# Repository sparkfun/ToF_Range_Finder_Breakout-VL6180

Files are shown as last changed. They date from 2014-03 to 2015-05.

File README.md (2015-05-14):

SparkFun ToF Range Finder Breakout - VL6180
===========================================

SparkFun ToF Range Finder Breakout - VL6180

[*SparkFun ToF Range Finder Breakout - VL6180 (SEN-12784)*](https://www.sparkfun.com/products/12784)

This is a breakout board for the VL6180 Baby Bear time of flight range finder.
The VL6180 is actually a 3-in-1 package that combines an IR emitter, a range sensor, and an ambient light sensor together for you to easily use. 

Repository Contents
-------------------
* **/Hardware** - All Eagle design files (.brd, .sch)
* **/Libraries** - All Arduino libraries and board examples
* **/Production** - Test bed files and production panel files

Documentation
--------------
* **[Library](https://github.com/sparkfun/SparkFun_ToF_Range_Finder-VL6180_Arduino_Library)** - Arduino  library for the VL6180.
* **[Hookup Guide](https://learn.sparkfun.com/tutorials/vl6180-hookup-guide)** - Basic hookup guide for the VL6180.
* **[SparkFun Fritzing repo](https://github.com/sparkfun/Fritzing_Parts)** - Fritzing diagrams for SparkFun products.
* **[SparkFun 3D Model repo](https://github.com/sparkfun/3D_Models)** - 3D models of SparkFun products. 

License Information
-------------------
This product is _**open source**_! 

The **hardware** is released under [Creative Commons ShareAlike 4.0 International](https://creativecommons.org/licenses/by-sa/4.0/).

The **code** is beerware; if you see me (or any other SparkFun employee) at the local, and you've found our code helpful, please buy us a round!

Please use, reuse, and modify these files as you see fit. Please maintain attribution to SparkFun Electronics and release anything derivative under the same license.

Distributed as-is; no warranty is given.

- Your friends at SparkFun.

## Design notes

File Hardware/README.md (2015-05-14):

SparkFun <PRODUCT NAME> Design Files
=====================================

The .sch and .brd files hare are Eagle CAD schematic and PCB design files from SparkFun Electronics.
A freeware version of Eagle can be found [here](http://www.cadsoftusa.com/download-eagle/freeware/). 

License
---------
This product is open source! 
The hardware is released under [Creative Commons ShareAlike 4.0 International](https://creativecommons.org/licenses/by-sa/4.0/).

Please use, reuse, and modify these files as you see fit. Please maintain attribution to SparkFun Electronics and release anything derivative under the same license.

Distributed as-is; no warranty is given.

- Your friends at SparkFun.

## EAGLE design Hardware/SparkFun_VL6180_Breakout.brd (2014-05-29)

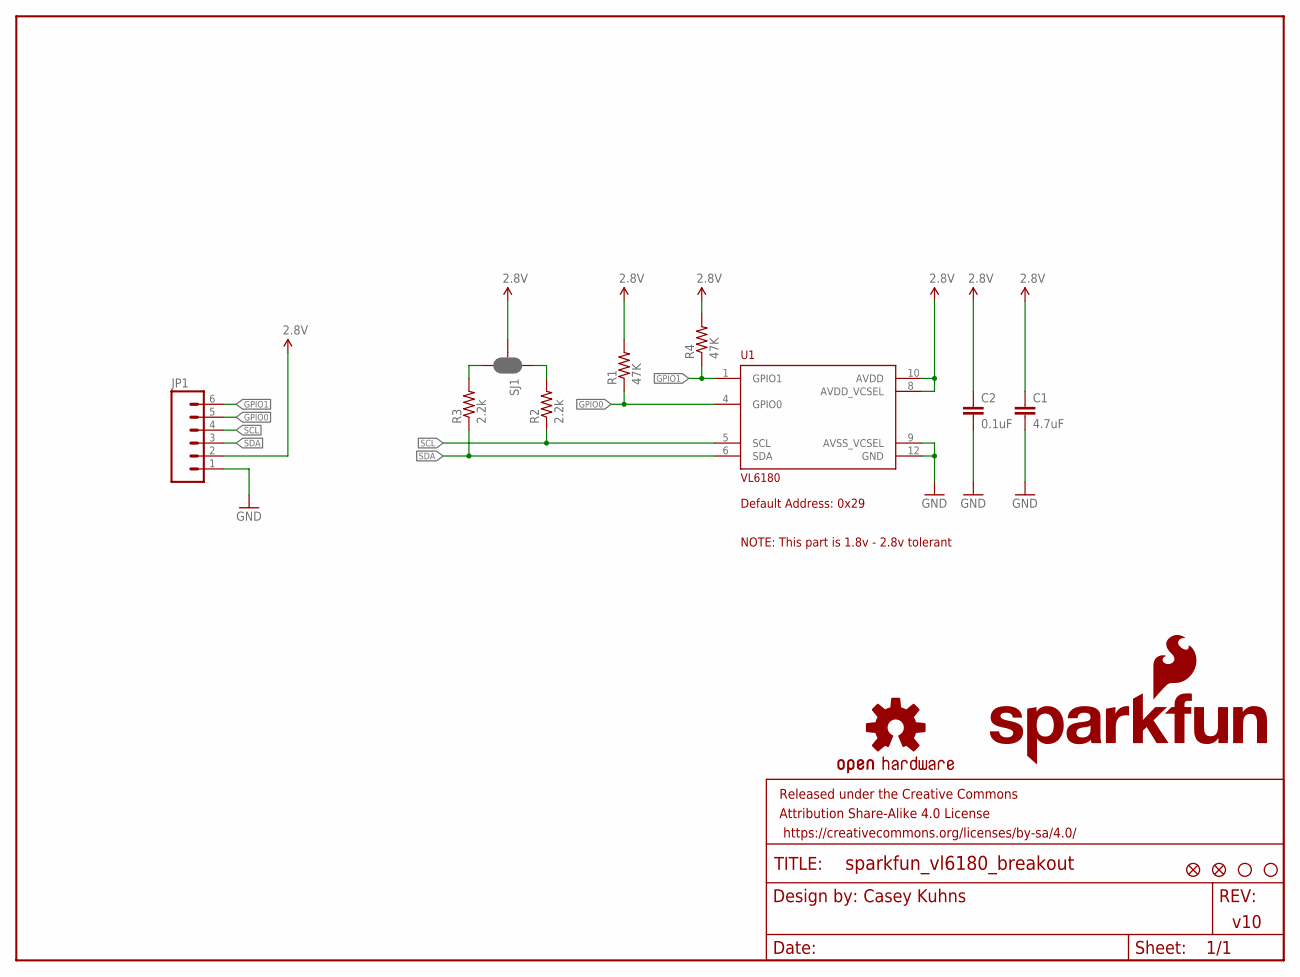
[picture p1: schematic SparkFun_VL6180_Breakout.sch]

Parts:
C1: 4.7uF; 0603-CAP
C2: 0.1uF; 0603-CAP
FID1, FID2: FIDUCIAL1X2; FIDUCIAL-1X2
FRAME1: FRAME-LETTER; CREATIVE_COMMONS
JP1: M06SIP; 1X06
LOGO1: SFE_LOGO_NAME_FLAME.1_INCH; SFE_LOGO_NAME_FLAME_.1
LOGO2: OSHW-LOGOS; OSHW-LOGO-S
R1, R4: 47K; 0603-RES
R2, R3: 2.2k; 0603-RES
SJ1: JUMPER-PAD-3-NC_BY_PASTE; PAD-JUMPER-3-NC_BY_PASTE_YES_SILK_FULL_BOX
STANDOFF1, STANDOFF2: STAND-OFF
U1: VL6180

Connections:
2.8V: C1.1, C2.1, JP1.2, R1.2, R4.2, SJ1.2, U1.8 (AVDD_VCSEL), U1.10 (AVDD)
GND: C1.2, C2.2, JP1.1, U1.9 (AVSS_VCSEL), U1.12 (GND)
GPIO0: JP1.5, R1.1, U1.4 (GPIO0)
GPIO1: JP1.6, R4.1, U1.1 (GPIO1)
unnamed: R2.2, SJ1.1
unnamed: R3.2, SJ1.3
SCL: JP1.4, R2.1, U1.5 (SCL)
SDA: JP1.3, R3.1, U1.6 (SDA)

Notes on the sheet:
Casey Kuhns
v10
Default Address: 0x29
NOTE: This part is 1.8v - 2.8v tolerant

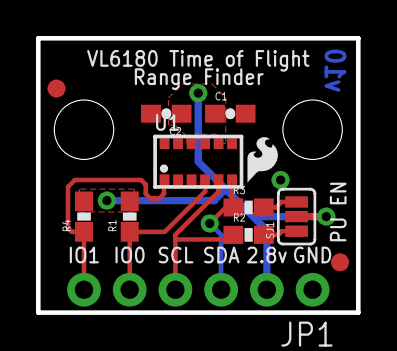
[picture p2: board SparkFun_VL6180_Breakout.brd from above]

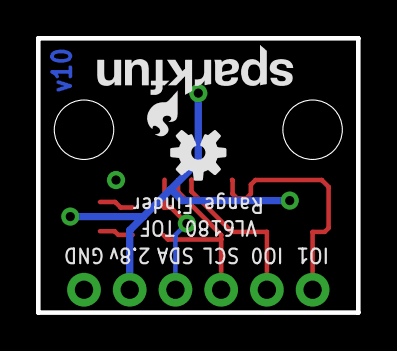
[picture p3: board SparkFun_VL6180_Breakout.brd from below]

Board: 2 copper layers, 17.8 x 15.2 mm, 17 parts (2 on the bottom side), 8 nets.

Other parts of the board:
U$2: SFE_LOGO_FLAME_.1

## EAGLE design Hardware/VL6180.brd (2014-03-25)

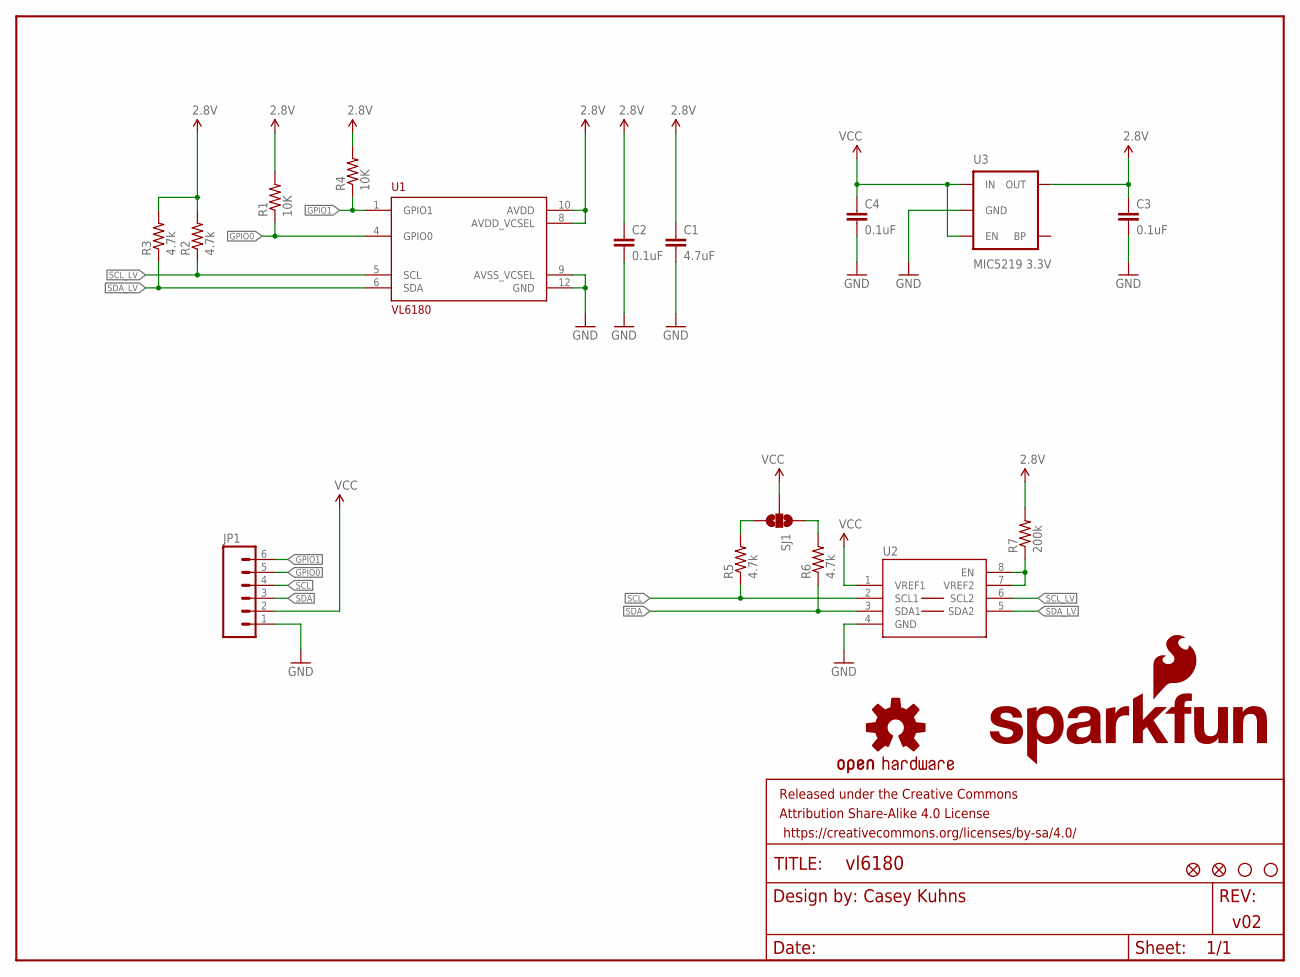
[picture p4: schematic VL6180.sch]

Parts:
C1: 4.7uF; 0603-CAP
C2, C3, C4: 0.1uF; 0603-CAP
FID1, FID2: FIDUCIAL1X2; FIDUCIAL-1X2
FRAME1: FRAME-LETTER; CREATIVE_COMMONS
JP1: M06SIP; 1X06
LOGO1: SFE_LOGO_NAME_FLAME.1_INCH; SFE_LOGO_NAME_FLAME_.1
LOGO2: OSHW-LOGOS; OSHW-LOGO-S
R1, R4: 10K; 0603-RES
R2, R3, R5, R6: 4.7k; 0603
R7: 200k; 0603-RES
SJ1: SOLDERJUMPER_2WAYPASTE1&2&3; SJ_3_PASTE1&2&3
STANDOFF1, STANDOFF2: STAND-OFF
U1: VL6180
U2: PCA9306; PSOP-8
U3: MIC5219 3.3V; SOT23-5

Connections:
2.8V: C1.1, C2.1, C3.1, R1.2, R2.2, R3.2, R4.2, R7.2, U1.8 (AVDD_VCSEL), U1.10 (AVDD), U3.5 (OUT)
GND: C1.2, C2.2, C3.2, C4.2, JP1.1, U1.9 (AVSS_VCSEL), U1.12 (GND), U2.4 (GND), U3.2 (GND)
GPIO0: JP1.5, R1.1, U1.4 (GPIO0)
GPIO1: JP1.6, R4.1, U1.1 (GPIO1)
unnamed: R7.1, U2.7 (VREF2), U2.8 (EN)
unnamed: R6.2, SJ1.1
unnamed: R5.2, SJ1.3
SCL: JP1.4, R5.1, U2.2 (SCL1)
SCL_LV: R2.1, U1.5 (SCL), U2.6 (SCL2)
SDA: JP1.3, R6.1, U2.3 (SDA1)
SDA_LV: R3.1, U1.6 (SDA), U2.5 (SDA2)
VCC: C4.1, JP1.2, SJ1.2, U2.1 (VREF1), U3.1 (IN), U3.3 (EN)

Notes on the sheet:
Casey Kuhns
v02

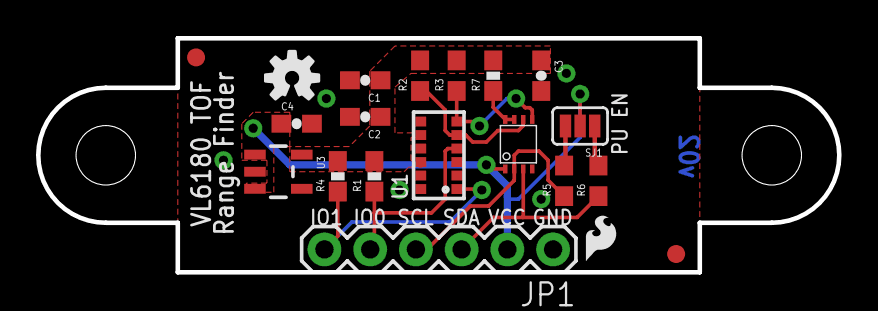
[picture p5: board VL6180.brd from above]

Board: 2 copper layers, 44.5 x 13.0 mm, 24 parts (1 on the bottom side), 12 nets.

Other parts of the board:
U$2: SFE_LOGO_FLAME_.1

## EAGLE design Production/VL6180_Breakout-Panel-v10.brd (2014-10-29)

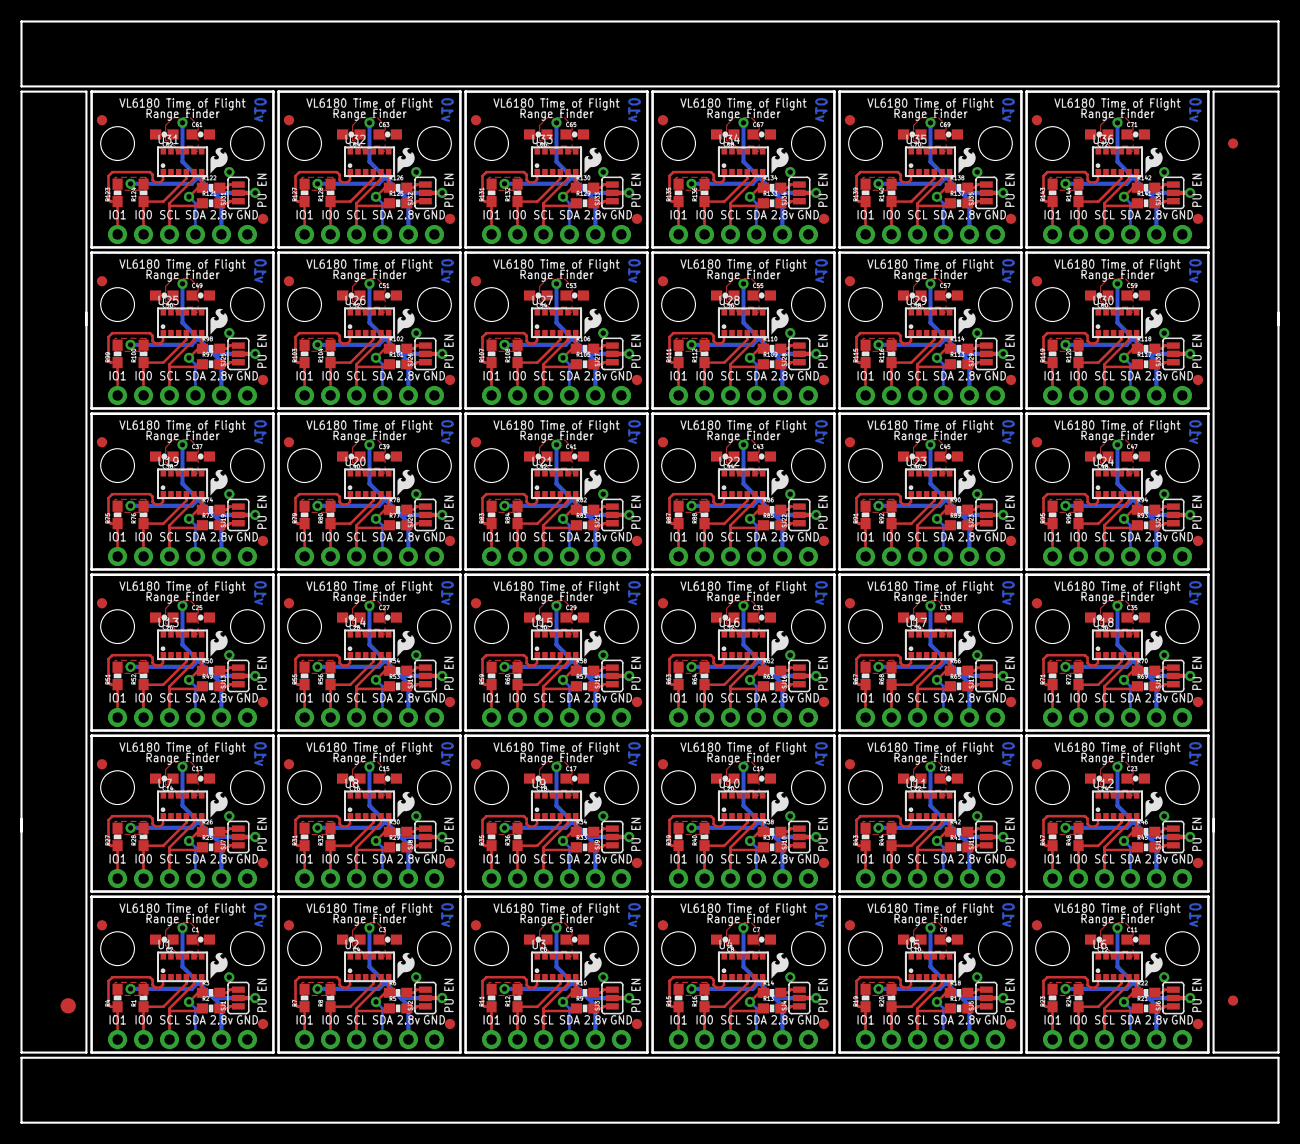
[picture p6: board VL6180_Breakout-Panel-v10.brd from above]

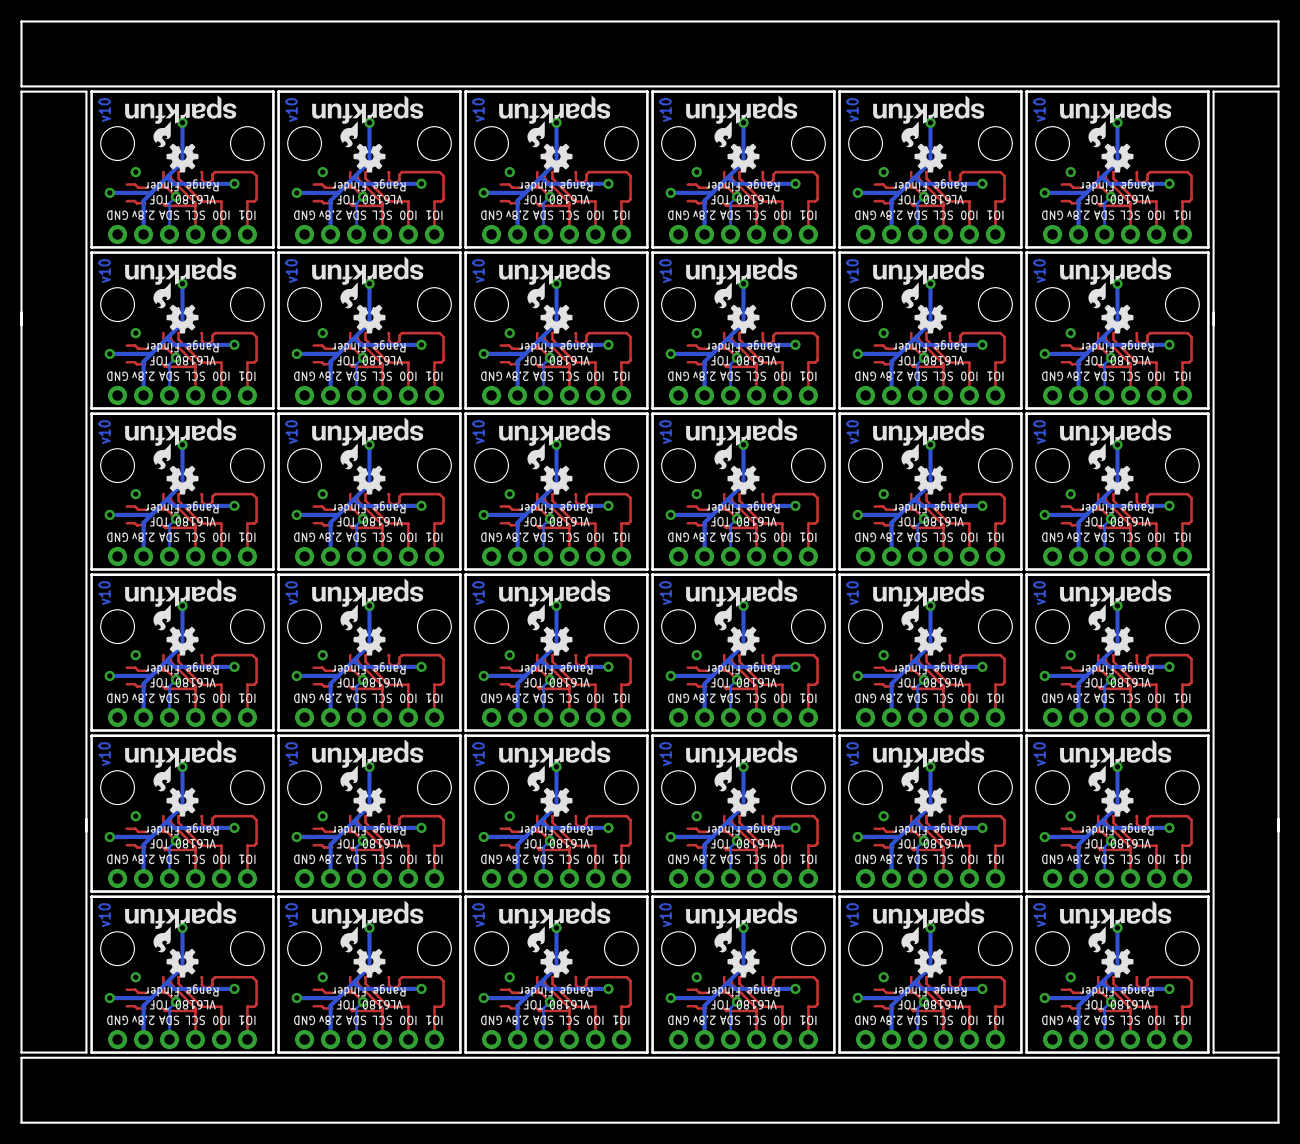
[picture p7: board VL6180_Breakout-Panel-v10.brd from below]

Board: 2 copper layers, 122.9 x 107.7 mm, 579 parts (72 on the bottom side), 288 nets.

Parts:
C1, C3, C5, C7, C9, C11, C13, C15, C17, C19, C21, C23, C25, C27, C29, C31, C33, C35, C37, C39, C41, C43, C45, C47, C49, C51, C53, C55, C57, C59, C61, C63, C65, C67, C69, C71: 4.7uF; 0603-CAP
C2, C4, C6, C8, C10, C12, C14, C16, C18, C20, C22, C24, C26, C28, C30, C32, C34, C36, C38, C40, C42, C44, C46, C48, C50, C52, C54, C56, C58, C60, C62, C64, C66, C68, C70, C72: 0.1uF; 0603-CAP
E$1: FIDUCIAL-1.5X3
E$4, E$6: FIDUCIAL-1X2
FID1, FID2, FID3, FID4, FID5, FID6, FID7, FID8, FID9, FID10, FID11, FID12, FID13, FID14, FID15, FID16, FID17, FID18, FID19, FID20, FID21, FID22, FID23, FID24, FID25, FID26, FID27, FID28, FID29, FID30, FID31, FID32, FID33, FID34, FID35, FID36, FID37, FID38, FID39, FID40, FID41, FID42, FID43, FID44, FID45, FID46, FID47, FID48, FID49, FID50, FID51, FID52, FID53, FID54, FID55, FID56, FID57, FID58, FID59, FID60, FID61, FID62, FID63, FID64, FID65, FID66, FID67, FID68, FID69, FID70, FID71, FID72: FIDUCIAL1X2; FIDUCIAL-1X2
JP1, JP2, JP3, JP4, JP5, JP6, JP7, JP8, JP9, JP10, JP11, JP12, JP13, JP14, JP15, JP16, JP17, JP18, JP19, JP20, JP21, JP22, JP23, JP24, JP25, JP26, JP27, JP28, JP29, JP30, JP31, JP32, JP33, JP34, JP35, JP36: 1X06
LOGO1, LOGO3, LOGO5, LOGO7, LOGO9, LOGO11, LOGO13, LOGO15, LOGO17, LOGO19, LOGO21, LOGO23, LOGO25, LOGO27, LOGO29, LOGO31, LOGO33, LOGO35, LOGO37, LOGO39, LOGO41, LOGO43, LOGO45, LOGO47, LOGO49, LOGO51, LOGO53, LOGO55, LOGO57, LOGO59, LOGO61, LOGO63, LOGO65, LOGO67, LOGO69, LOGO71: SFE_LOGO_NAME_FLAME.1_INCH; SFE_LOGO_NAME_FLAME_.1
LOGO2, LOGO4, LOGO6, LOGO8, LOGO10, LOGO12, LOGO14, LOGO16, LOGO18, LOGO20, LOGO22, LOGO24, LOGO26, LOGO28, LOGO30, LOGO32, LOGO34, LOGO36, LOGO38, LOGO40, LOGO42, LOGO44, LOGO46, LOGO48, LOGO50, LOGO52, LOGO54, LOGO56, LOGO58, LOGO60, LOGO62, LOGO64, LOGO66, LOGO68, LOGO70, LOGO72: OSHW-LOGOS; OSHW-LOGO-S
R1, R4, R7, R8, R11, R12, R15, R16, R19, R20, R23, R24, R27, R28, R31, R32, R35, R36, R39, R40, R43, R44, R47, R48, R51, R52, R55, R56, R59, R60, R63, R64, R67, R68, R71, R72, R75, R76, R79, R80, R83, R84, R87, R88, R91, R92, R95, R96, R99, R100, R103, R104, R107, R108, R111, R112, R115, R116, R119, R120, R123, R124, R127, R128, R131, R132, R135, R136, R139, R140, R143, R144: 47K; 0603-RES
R2, R3, R5, R6, R9, R10, R13, R14, R17, R18, R21, R22, R25, R26, R29, R30, R33, R34, R37, R38, R41, R42, R45, R46, R49, R50, R53, R54, R57, R58, R61, R62, R65, R66, R69, R70, R73, R74, R77, R78, R81, R82, R85, R86, R89, R90, R93, R94, R97, R98, R101, R102, R105, R106, R109, R110, R113, R114, R117, R118, R121, R122, R125, R126, R129, R130, R133, R134, R137, R138, R141, R142: 2.2k; 0603-RES
SJ1, SJ2, SJ3, SJ4, SJ5, SJ6, SJ7, SJ8, SJ9, SJ10, SJ11, SJ12, SJ13, SJ14, SJ15, SJ16, SJ17, SJ18, SJ19, SJ20, SJ21, SJ22, SJ23, SJ24, SJ25, SJ26, SJ27, SJ28, SJ29, SJ30, SJ31, SJ32, SJ33, SJ34, SJ35, SJ36: PAD-JUMPER-3-NC_BY_PASTE_YES_SILK_FULL_BOX
STANDOFF1, STANDOFF2, STANDOFF3, STANDOFF4, STANDOFF5, STANDOFF6, STANDOFF7, STANDOFF8, STANDOFF9, STANDOFF10, STANDOFF11, STANDOFF12, STANDOFF13, STANDOFF14, STANDOFF15, STANDOFF16, STANDOFF17, STANDOFF18, STANDOFF19, STANDOFF20, STANDOFF21, STANDOFF22, STANDOFF23, STANDOFF24, STANDOFF25, STANDOFF26, STANDOFF27, STANDOFF28, STANDOFF29, STANDOFF30, STANDOFF31, STANDOFF32, STANDOFF33, STANDOFF34, STANDOFF35, STANDOFF36, STANDOFF37, STANDOFF38, STANDOFF39, STANDOFF40, STANDOFF41, STANDOFF42, STANDOFF43, STANDOFF44, STANDOFF45, STANDOFF46, STANDOFF47, STANDOFF48, STANDOFF49, STANDOFF50, STANDOFF51, STANDOFF52, STANDOFF53, STANDOFF54, STANDOFF55, STANDOFF56, STANDOFF57, STANDOFF58, STANDOFF59, STANDOFF60, STANDOFF61, STANDOFF62, STANDOFF63, STANDOFF64, STANDOFF65, STANDOFF66, STANDOFF67, STANDOFF68, STANDOFF69, STANDOFF70, STANDOFF71, STANDOFF72: STAND-OFF
U1, U2, U3, U4, U5, U6, U7, U8, U9, U10, U11, U12, U13, U14, U15, U16, U17, U18, U19, U20, U21, U22, U23, U24, U25, U26, U27, U28, U29, U30, U31, U32, U33, U34, U35, U36: VL6180
U$1, U$2, U$3, U$4, U$5, U$6, U$7, U$8, U$9, U$10, U$11, U$12, U$13, U$14, U$15, U$16, U$17, U$18, U$19, U$20, U$21, U$22, U$23, U$24, U$25, U$26, U$27, U$28, U$29, U$30, U$31, U$32, U$33, U$34, U$35, U$36: SFE_LOGO_FLAME_.1

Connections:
2.8V: C1.1, C2.1, JP1.2, R1.2, R4.2, SJ1.2, U1.8, U1.10
2.8V1: C3.1, C4.1, JP2.2, R7.2, R8.2, SJ2.2, U2.8, U2.10
2.8V2: C5.1, C6.1, JP3.2, R11.2, R12.2, SJ3.2, U3.8, U3.10
2.8V3: C7.1, C8.1, JP4.2, R15.2, R16.2, SJ4.2, U4.8, U4.10
2.8V4: C9.1, C10.1, JP5.2, R19.2, R20.2, SJ5.2, U5.8, U5.10
2.8V5: C11.1, C12.1, JP6.2, R23.2, R24.2, SJ6.2, U6.8, U6.10
2.8V6: C13.1, C14.1, JP7.2, R27.2, R28.2, SJ7.2, U7.8, U7.10
2.8V7: C15.1, C16.1, JP8.2, R31.2, R32.2, SJ8.2, U8.8, U8.10
2.8V8: C17.1, C18.1, JP9.2, R35.2, R36.2, SJ9.2, U9.8, U9.10
2.8V9: C19.1, C20.1, JP10.2, R39.2, R40.2, SJ10.2, U10.8, U10.10
2.8V10: C21.1, C22.1, JP11.2, R43.2, R44.2, SJ11.2, U11.8, U11.10
2.8V11: C23.1, C24.1, JP12.2, R47.2, R48.2, SJ12.2, U12.8, U12.10
2.8V12: C25.1, C26.1, JP13.2, R51.2, R52.2, SJ13.2, U13.8, U13.10
2.8V13: C27.1, C28.1, JP14.2, R55.2, R56.2, SJ14.2, U14.8, U14.10
2.8V14: C29.1, C30.1, JP15.2, R59.2, R60.2, SJ15.2, U15.8, U15.10
2.8V15: C31.1, C32.1, JP16.2, R63.2, R64.2, SJ16.2, U16.8, U16.10
2.8V16: C33.1, C34.1, JP17.2, R67.2, R68.2, SJ17.2, U17.8, U17.10
2.8V17: C35.1, C36.1, JP18.2, R71.2, R72.2, SJ18.2, U18.8, U18.10
2.8V18: C37.1, C38.1, JP19.2, R75.2, R76.2, SJ19.2, U19.8, U19.10
2.8V19: C39.1, C40.1, JP20.2, R79.2, R80.2, SJ20.2, U20.8, U20.10
2.8V20: C41.1, C42.1, JP21.2, R83.2, R84.2, SJ21.2, U21.8, U21.10
2.8V21: C43.1, C44.1, JP22.2, R87.2, R88.2, SJ22.2, U22.8, U22.10
2.8V22: C45.1, C46.1, JP23.2, R91.2, R92.2, SJ23.2, U23.8, U23.10
2.8V23: C47.1, C48.1, JP24.2, R95.2, R96.2, SJ24.2, U24.8, U24.10
2.8V24: C49.1, C50.1, JP25.2, R99.2, R100.2, SJ25.2, U25.8, U25.10
2.8V25: C51.1, C52.1, JP26.2, R103.2, R104.2, SJ26.2, U26.8, U26.10
2.8V26: C53.1, C54.1, JP27.2, R107.2, R108.2, SJ27.2, U27.8, U27.10
2.8V27: C55.1, C56.1, JP28.2, R111.2, R112.2, SJ28.2, U28.8, U28.10
2.8V28: C57.1, C58.1, JP29.2, R115.2, R116.2, SJ29.2, U29.8, U29.10
2.8V29: C59.1, C60.1, JP30.2, R119.2, R120.2, SJ30.2, U30.8, U30.10
2.8V30: C61.1, C62.1, JP31.2, R123.2, R124.2, SJ31.2, U31.8, U31.10
2.8V31: C63.1, C64.1, JP32.2, R127.2, R128.2, SJ32.2, U32.8, U32.10
2.8V32: C65.1, C66.1, JP33.2, R131.2, R132.2, SJ33.2, U33.8, U33.10
2.8V33: C67.1, C68.1, JP34.2, R135.2, R136.2, SJ34.2, U34.8, U34.10
2.8V34: C69.1, C70.1, JP35.2, R139.2, R140.2, SJ35.2, U35.8, U35.10
2.8V35: C71.1, C72.1, JP36.2, R143.2, R144.2, SJ36.2, U36.8, U36.10
GND: C1.2, C2.2, JP1.1, U1.9, U1.12
GND1: C3.2, C4.2, JP2.1, U2.9, U2.12
GND2: C5.2, C6.2, JP3.1, U3.9, U3.12
GND3: C7.2, C8.2, JP4.1, U4.9, U4.12
GND4: C9.2, C10.2, JP5.1, U5.9, U5.12
GND5: C11.2, C12.2, JP6.1, U6.9, U6.12
GND6: C13.2, C14.2, JP7.1, U7.9, U7.12
GND7: C15.2, C16.2, JP8.1, U8.9, U8.12
GND8: C17.2, C18.2, JP9.1, U9.9, U9.12
GND9: C19.2, C20.2, JP10.1, U10.9, U10.12
GND10: C21.2, C22.2, JP11.1, U11.9, U11.12
GND11: C23.2, C24.2, JP12.1, U12.9, U12.12
GND12: C25.2, C26.2, JP13.1, U13.9, U13.12
GND13: C27.2, C28.2, JP14.1, U14.9, U14.12
GND14: C29.2, C30.2, JP15.1, U15.9, U15.12
GND15: C31.2, C32.2, JP16.1, U16.9, U16.12
GND16: C33.2, C34.2, JP17.1, U17.9, U17.12
GND17: C35.2, C36.2, JP18.1, U18.9, U18.12
GND18: C37.2, C38.2, JP19.1, U19.9, U19.12
GND19: C39.2, C40.2, JP20.1, U20.9, U20.12
GND20: C41.2, C42.2, JP21.1, U21.9, U21.12
GND21: C43.2, C44.2, JP22.1, U22.9, U22.12
GND22: C45.2, C46.2, JP23.1, U23.9, U23.12
GND23: C47.2, C48.2, JP24.1, U24.9, U24.12
GND24: C49.2, C50.2, JP25.1, U25.9, U25.12
GND25: C51.2, C52.2, JP26.1, U26.9, U26.12
GND26: C53.2, C54.2, JP27.1, U27.9, U27.12
GND27: C55.2, C56.2, JP28.1, U28.9, U28.12
GND28: C57.2, C58.2, JP29.1, U29.9, U29.12
GND29: C59.2, C60.2, JP30.1, U30.9, U30.12
GND30: C61.2, C62.2, JP31.1, U31.9, U31.12
GND31: C63.2, C64.2, JP32.1, U32.9, U32.12
GND32: C65.2, C66.2, JP33.1, U33.9, U33.12
GND33: C67.2, C68.2, JP34.1, U34.9, U34.12
GND34: C69.2, C70.2, JP35.1, U35.9, U35.12
GND35: C71.2, C72.2, JP36.1, U36.9, U36.12
GPIO0: JP1.5, R1.1, U1.4
GPIO1: JP1.6, R4.1, U1.1
GPIO2: JP2.5, R8.1, U2.4
GPIO3: JP2.6, R7.1, U2.1
GPIO4: JP3.5, R12.1, U3.4
GPIO5: JP3.6, R11.1, U3.1
GPIO6: JP4.5, R16.1, U4.4
GPIO7: JP4.6, R15.1, U4.1
GPIO8: JP5.5, R20.1, U5.4
GPIO9: JP5.6, R19.1, U5.1
GPIO10: JP6.5, R24.1, U6.4
GPIO11: JP6.6, R23.1, U6.1
GPIO12: JP7.5, R28.1, U7.4
GPIO13: JP7.6, R27.1, U7.1
GPIO14: JP8.5, R32.1, U8.4
GPIO15: JP8.6, R31.1, U8.1
GPIO16: JP9.5, R36.1, U9.4
GPIO17: JP9.6, R35.1, U9.1
GPIO18: JP10.5, R40.1, U10.4
GPIO19: JP10.6, R39.1, U10.1
GPIO20: JP11.5, R44.1, U11.4
GPIO21: JP11.6, R43.1, U11.1
GPIO22: JP12.5, R48.1, U12.4
GPIO23: JP12.6, R47.1, U12.1
GPIO24: JP13.5, R52.1, U13.4
GPIO25: JP13.6, R51.1, U13.1
GPIO26: JP14.5, R56.1, U14.4
GPIO27: JP14.6, R55.1, U14.1
GPIO28: JP15.5, R60.1, U15.4
GPIO29: JP15.6, R59.1, U15.1
GPIO30: JP16.5, R64.1, U16.4
GPIO31: JP16.6, R63.1, U16.1
GPIO32: JP17.5, R68.1, U17.4
GPIO33: JP17.6, R67.1, U17.1
GPIO34: JP18.5, R72.1, U18.4
GPIO35: JP18.6, R71.1, U18.1
GPIO36: JP19.5, R76.1, U19.4
GPIO37: JP19.6, R75.1, U19.1
GPIO38: JP20.5, R80.1, U20.4
GPIO39: JP20.6, R79.1, U20.1
GPIO40: JP21.5, R84.1, U21.4
GPIO41: JP21.6, R83.1, U21.1
GPIO42: JP22.5, R88.1, U22.4
GPIO43: JP22.6, R87.1, U22.1
GPIO44: JP23.5, R92.1, U23.4
GPIO45: JP23.6, R91.1, U23.1
GPIO46: JP24.5, R96.1, U24.4
GPIO47: JP24.6, R95.1, U24.1
GPIO48: JP25.5, R100.1, U25.4
GPIO49: JP25.6, R99.1, U25.1
GPIO50: JP26.5, R104.1, U26.4
GPIO51: JP26.6, R103.1, U26.1
GPIO52: JP27.5, R108.1, U27.4
GPIO53: JP27.6, R107.1, U27.1
GPIO54: JP28.5, R112.1, U28.4
GPIO55: JP28.6, R111.1, U28.1
GPIO56: JP29.5, R116.1, U29.4
GPIO57: JP29.6, R115.1, U29.1
GPIO58: JP30.5, R120.1, U30.4
GPIO59: JP30.6, R119.1, U30.1
GPIO60: JP31.5, R124.1, U31.4
GPIO61: JP31.6, R123.1, U31.1
GPIO62: JP32.5, R128.1, U32.4
GPIO63: JP32.6, R127.1, U32.1
GPIO64: JP33.5, R132.1, U33.4
GPIO65: JP33.6, R131.1, U33.1
GPIO66: JP34.5, R136.1, U34.4
GPIO67: JP34.6, R135.1, U34.1
GPIO68: JP35.5, R140.1, U35.4
GPIO69: JP35.6, R139.1, U35.1
GPIO70: JP36.5, R144.1, U36.4
GPIO71: JP36.6, R143.1, U36.1
unnamed: R2.2, SJ1.1
unnamed: R3.2, SJ1.3
unnamed: R5.2, SJ2.1
unnamed: R6.2, SJ2.3
unnamed: R9.2, SJ3.1
unnamed: R10.2, SJ3.3
unnamed: R13.2, SJ4.1
unnamed: R14.2, SJ4.3
unnamed: R17.2, SJ5.1
unnamed: R18.2, SJ5.3
unnamed: R21.2, SJ6.1
unnamed: R22.2, SJ6.3
unnamed: R25.2, SJ7.1
unnamed: R26.2, SJ7.3
unnamed: R29.2, SJ8.1
unnamed: R30.2, SJ8.3
unnamed: R33.2, SJ9.1
unnamed: R34.2, SJ9.3
unnamed: R37.2, SJ10.1
unnamed: R38.2, SJ10.3
unnamed: R41.2, SJ11.1
unnamed: R42.2, SJ11.3
unnamed: R45.2, SJ12.1
unnamed: R46.2, SJ12.3
unnamed: R49.2, SJ13.1
unnamed: R50.2, SJ13.3
unnamed: R53.2, SJ14.1
unnamed: R54.2, SJ14.3
unnamed: R57.2, SJ15.1
unnamed: R58.2, SJ15.3
unnamed: R61.2, SJ16.1
unnamed: R62.2, SJ16.3
unnamed: R65.2, SJ17.1
unnamed: R66.2, SJ17.3
unnamed: R69.2, SJ18.1
unnamed: R70.2, SJ18.3
unnamed: R73.2, SJ19.1
unnamed: R74.2, SJ19.3
unnamed: R77.2, SJ20.1
unnamed: R78.2, SJ20.3
unnamed: R81.2, SJ21.1
unnamed: R82.2, SJ21.3
unnamed: R85.2, SJ22.1
unnamed: R86.2, SJ22.3
unnamed: R89.2, SJ23.1
unnamed: R90.2, SJ23.3
unnamed: R93.2, SJ24.1
unnamed: R94.2, SJ24.3
unnamed: R97.2, SJ25.1
unnamed: R98.2, SJ25.3
unnamed: R101.2, SJ26.1
unnamed: R102.2, SJ26.3
unnamed: R105.2, SJ27.1
unnamed: R106.2, SJ27.3
unnamed: R109.2, SJ28.1
unnamed: R110.2, SJ28.3
unnamed: R113.2, SJ29.1
unnamed: R114.2, SJ29.3
unnamed: R117.2, SJ30.1
unnamed: R118.2, SJ30.3
unnamed: R121.2, SJ31.1
unnamed: R122.2, SJ31.3
unnamed: R125.2, SJ32.1
unnamed: R126.2, SJ32.3
unnamed: R129.2, SJ33.1
unnamed: R130.2, SJ33.3
unnamed: R133.2, SJ34.1
unnamed: R134.2, SJ34.3
unnamed: R137.2, SJ35.1
unnamed: R138.2, SJ35.3
unnamed: R141.2, SJ36.1
unnamed: R142.2, SJ36.3
SCL: JP1.4, R2.1, U1.5
SCL1: JP2.4, R5.1, U2.5
SCL2: JP3.4, R9.1, U3.5
SCL3: JP4.4, R13.1, U4.5
SCL4: JP5.4, R17.1, U5.5
SCL5: JP6.4, R21.1, U6.5
SCL6: JP7.4, R25.1, U7.5
SCL7: JP8.4, R29.1, U8.5
SCL8: JP9.4, R33.1, U9.5
SCL9: JP10.4, R37.1, U10.5
SCL10: JP11.4, R41.1, U11.5
SCL11: JP12.4, R45.1, U12.5
SCL12: JP13.4, R49.1, U13.5
SCL13: JP14.4, R53.1, U14.5
SCL14: JP15.4, R57.1, U15.5
SCL15: JP16.4, R61.1, U16.5
SCL16: JP17.4, R65.1, U17.5
SCL17: JP18.4, R69.1, U18.5
SCL18: JP19.4, R73.1, U19.5
SCL19: JP20.4, R77.1, U20.5
SCL20: JP21.4, R81.1, U21.5
SCL21: JP22.4, R85.1, U22.5
SCL22: JP23.4, R89.1, U23.5
SCL23: JP24.4, R93.1, U24.5
SCL24: JP25.4, R97.1, U25.5
SCL25: JP26.4, R101.1, U26.5
SCL26: JP27.4, R105.1, U27.5
SCL27: JP28.4, R109.1, U28.5
SCL28: JP29.4, R113.1, U29.5
SCL29: JP30.4, R117.1, U30.5
SCL30: JP31.4, R121.1, U31.5
SCL31: JP32.4, R125.1, U32.5
SCL32: JP33.4, R129.1, U33.5
SCL33: JP34.4, R133.1, U34.5
SCL34: JP35.4, R137.1, U35.5
SCL35: JP36.4, R141.1, U36.5
SDA: JP1.3, R3.1, U1.6
SDA1: JP2.3, R6.1, U2.6
SDA2: JP3.3, R10.1, U3.6
SDA3: JP4.3, R14.1, U4.6
SDA4: JP5.3, R18.1, U5.6
SDA5: JP6.3, R22.1, U6.6
SDA6: JP7.3, R26.1, U7.6
SDA7: JP8.3, R30.1, U8.6
SDA8: JP9.3, R34.1, U9.6
SDA9: JP10.3, R38.1, U10.6
SDA10: JP11.3, R42.1, U11.6
SDA11: JP12.3, R46.1, U12.6
SDA12: JP13.3, R50.1, U13.6
SDA13: JP14.3, R54.1, U14.6
SDA14: JP15.3, R58.1, U15.6
SDA15: JP16.3, R62.1, U16.6
SDA16: JP17.3, R66.1, U17.6
SDA17: JP18.3, R70.1, U18.6
SDA18: JP19.3, R74.1, U19.6
SDA19: JP20.3, R78.1, U20.6
SDA20: JP21.3, R82.1, U21.6
SDA21: JP22.3, R86.1, U22.6
SDA22: JP23.3, R90.1, U23.6
SDA23: JP24.3, R94.1, U24.6
SDA24: JP25.3, R98.1, U25.6
SDA25: JP26.3, R102.1, U26.6
SDA26: JP27.3, R106.1, U27.6
SDA27: JP28.3, R110.1, U28.6
SDA28: JP29.3, R114.1, U29.6
SDA29: JP30.3, R118.1, U30.6
SDA30: JP31.3, R122.1, U31.6
SDA31: JP32.3, R126.1, U32.6
SDA32: JP33.3, R130.1, U33.6
SDA33: JP34.3, R134.1, U34.6
SDA34: JP35.3, R138.1, U35.6
SDA35: JP36.3, R142.1, U36.6

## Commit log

2014-02-21 initial commit with initial hardware layout
    [VL6180.brd, VL6180.sch]
2014-02-28 Boad Layout finished, looking for review
    [VL6180.brd, VL6180.sch]
2014-03-03 finished layout and added simple breakout board layout
    [VL6180_Breakout.brd, VL6180_Breakout.sch]
2014-03-03 changed VCC label on breakout to 2.8v to re-state 2.8v compatible
    [VL6180_Breakout.brd]
2014-03-04 Changed I2C EN to PU EN
    [VL6180.brd, VL6180_Breakout.brd]
2014-03-13 fixed flipped pin problem. 8-9 on the sensor were reversed somehow. All better :)
    [VL6180.brd, VL6180.sch, VL6180_Breakout.brd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]
2014-03-25 added pin 1 designator
    [VL6180.brd, VL6180.sch, VL6180_Breakout.brd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]
2014-05-01 modified: Hardware/VL6180_Breakout.brd modified: Hardware/VL6180_Breakout.sch renamed: Hardware/VL6180.brd -> Hardware/VL6180_Sensor.brd renamed: Hardware/VL6180.sch -> Hardware/VL6180_Sensor.sch
    Removed I2C level shifter and switched to Fet bases solution.
    New solderpaste footprint for VL6180 for improved reflow.
    updated all parts with Sparkle ID's
    [VL6180_Breakout.brd, VL6180_Breakout.sch, VL6180_Sensor.brd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]
2014-05-28 changed I2C resistors to 2.2k, added current limiting resistor on GPIO pins.
    [VL6180_Breakout.brd, VL6180_Breakout.sch, VL6180_Sensor.brd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]
2014-05-29 moved wire to clear resistor better, re-oriented Silkscreen to match direction of logo.
    [VL6180_Breakout.brd, VL6180_Sensor.brd]
2014-05-29 created Sensor panel v10
    [VL6180_Sensor-Panel-v10.brd]
2014-05-29 created breakout panel v10
    [VL6180_Breakout-Panel-v10.brd]
2015-01-23 worked on Library, currently functioning, building more features
2015-02-10 split repo
    [VL6180_Sensor-Panel-v10.brd, VL6180_Sensor.brd, VL6180_Sensor.sch]
2015-02-13 Updating README with product info
    [VL6180_Breakout-Panel-v10.brd]
2015-05-14 Fixing structure, naming conventions
    [SparkFun_VL6180_Breakout.brd, SparkFun_VL6180_Breakout.sch]
2015-05-14 Squashed 'Libraries/Arduino/' content from commit dd6cce0
    git-subtree-dir: Libraries/Arduino
    git-subtree-split: dd6cce03c074b9068238a3e29b15535ec5eadf2b

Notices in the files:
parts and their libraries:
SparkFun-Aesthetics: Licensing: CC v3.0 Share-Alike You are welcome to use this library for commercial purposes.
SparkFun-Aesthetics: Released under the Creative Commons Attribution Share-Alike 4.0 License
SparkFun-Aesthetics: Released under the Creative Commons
